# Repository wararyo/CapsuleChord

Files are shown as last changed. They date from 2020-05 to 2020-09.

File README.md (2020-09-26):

# CapsuleChord
An electronic instrument for playing chords, using the M5Stack

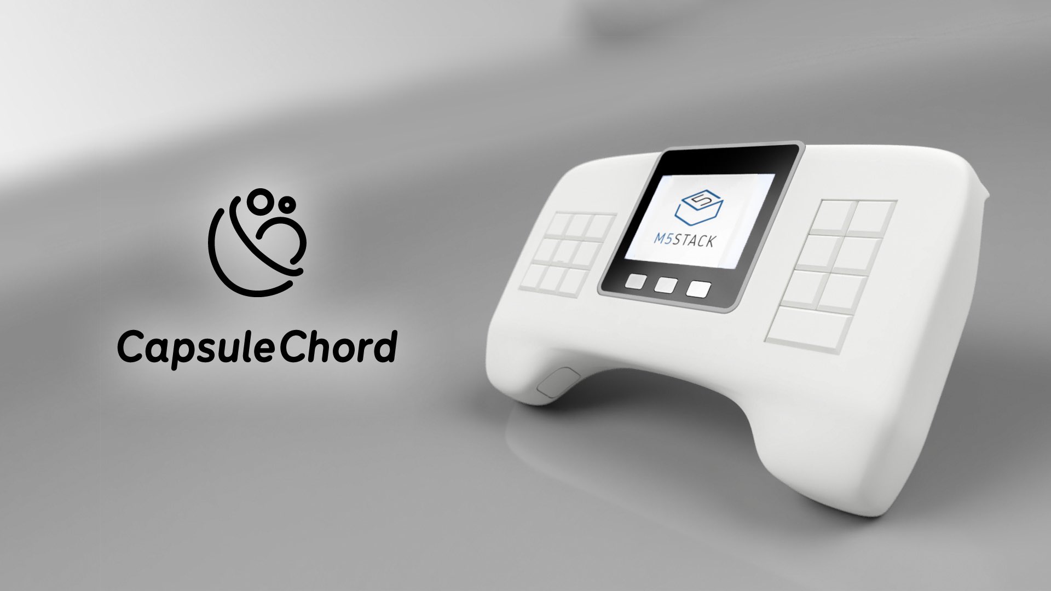
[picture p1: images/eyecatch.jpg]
eyecatch


The firmware in M5Stack is based on [M5Stack_BLEChorder](https://github.com/wararyo/m5chorder).
BLEChorder can be played alone on the M5Stack.

[🎥Introduction Video](https://youtu.be/JE3piJ5rN3A)

Currently this project is in progress.  
The latest information -> [#CapsuleChord](https://twitter.com/search?q=%23CapsuleChord&f=live) (Japanese)

**2020/09/26 3D model files are now available!**  
See `Case` directory.

## Features

* Easy to play chords
* Specify a diatonic code with the left keypad and modify it with the right keypad
* Can be connected with iOS/iPadOS/macOS/Windows via BLE (On Windows, requires MIDIberry and loopMIDI)

## Structure

* M5Stack Gray
* Keypad Controller(ATmega328P)
* Two keypads
* Two function buttons
* Two up-down sliders

## Required to make

### M5Stack

* M5Stack Gray
* M5Stack battery module
* M5Stack proto module

### Keypads

* ATmega328P
* 23 tactile switches
* 8 diodes

### Other

* Two 3pin connectors and sockets
* Two 8pin connectors and sockets
* Six 2M tapping screws (to mount keypads)
* Four 3M tapping scress (to close the casing)
* Two 3M tapping scress (to mount the M5Stack)
* AVRISP of some kind
* and a 3D printing environment :)

## Credits

* [M5TreeView](https://github.com/lovyan03/M5Stack_TreeView) by [lovyan03](https://github.com/lovyan03)
* [M5Stack 3DModel](https://botalab.tech/m5stack_cad_data/) by [botamochi6277](https://botalab.tech/)

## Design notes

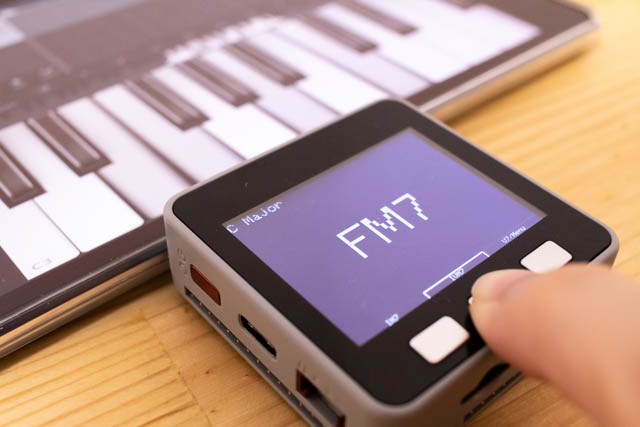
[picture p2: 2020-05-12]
M5Chorder/images/1.thumb.jpg

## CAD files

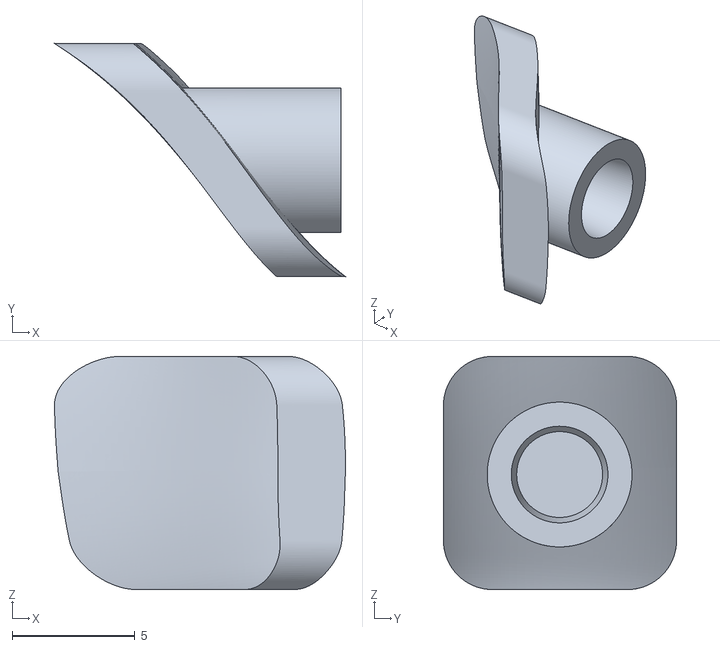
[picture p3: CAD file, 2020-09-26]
Case/sustain-right.stl
11.9 x 9.50 x 9.50

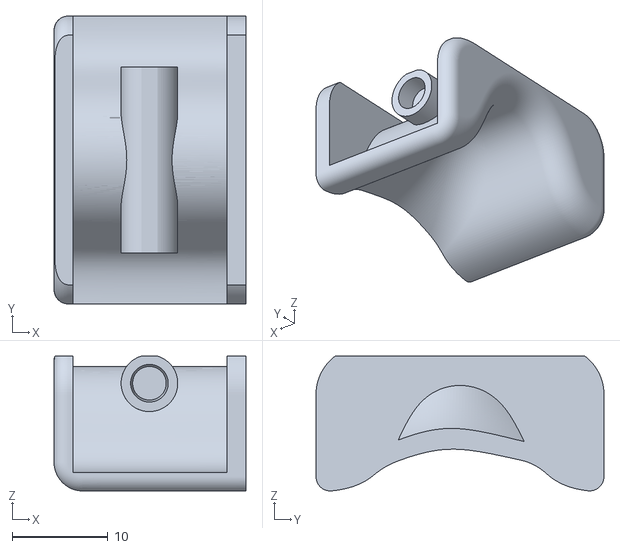
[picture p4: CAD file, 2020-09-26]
Case/back.stl
20.0 x 30.0 x 14.1

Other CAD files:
Case/function-left.stl

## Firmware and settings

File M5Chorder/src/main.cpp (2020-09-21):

#include <M5Stack.h>
#include <vector>
#include <Preferences.h>
#include "M5StackUpdater.h"
#include "BLEMidi.h"
#include "Chord.h"
#include "Scale.h"
#include "Keypad.h"
#include "Menu.h"
#include "KeyMap/KeyMap.h"
#include "Context.h"

#define DEVICE_NAME "BLEChorder"

std::vector<uint8_t> playingNotes;
bool seventh = false;
int option = 0;

// Initialize at setup()
Scale *scale;
int *centerNoteNo;
Context context;

M5ButtonDrawer buttonDrawer;

typedef std::vector<SettingItem*> si;
typedef std::vector<const char *> strs;
Settings settings(si{
  new SettingItemEnum("Mode",{"CapsuleChord","CAmDion","Presets"},0),
  new SettingItemScale("Scale",Scale(0)),
  new SettingItemEnum("Bass",{"None","C1","C2"},0),
  new SettingItemEnum("Voicing",{"Open","Closed"},0),
  new SettingItemNumeric("CenterNoteNo",24,81,60),
  new SettingItemDegreeChord("Custom 1", DegreeChord(4,Chord::Minor|Chord::MajorSeventh)),
  new SettingItemDegreeChord("Custom 2", DegreeChord(5,Chord::Minor|Chord::Seventh)),
  new SettingItem("Keymap",si{
    new SettingItemEnum("Fuction 1",{"Gyro","Sustain","Note","CC"},0),
    new SettingItemEnum("Fuction 2",{"Gyro","Sustain","Note","CC"},1)
  }),
  new SettingItemEnum("SustainBehavior",{"Normal","Trigger"},0)
});

enum Scene : uint8_t {
  Connection,
  Play,
  FunctionMenu,
  length
};

Scene currentScene = Scene::length; //Specify a value other than Connection in order to draw correctly at the first changeScene()
Scene requiredToChangeScene;

void changeScene(Scene scene) {
  //To draw at the end of loop(), set flag
  requiredToChangeScene = scene;
}

//Used only in setup() and the end of loop() Do not touch it anywhere else!
void _changeScene_raw() {
  M5.Lcd.clear();

  //終了処理
  switch(currentScene) {
  }

  //開始処理
  switch(requiredToChangeScene) {
    case Scene::Connection:
      M5.Lcd.setTextFont(1);
      M5.Lcd.setCursor(0, 48);
      M5.Lcd.setTextSize(4);
      M5.Lcd.println("CapsuleChord");
      M5.Lcd.setTextSize(2);
      M5.Lcd.println("BLE MIDI Chordpad Device\n");
      M5.Lcd.setTextSize(1);
      M5.Lcd.println("Advertising...");
      M5.Lcd.println("Press the button A to power off.");
    break;
    case Scene::Play:
      M5.Lcd.setCursor(0,0);
      M5.Lcd.setTextSize(2);
      M5.Lcd.println(scale->toString());
      buttonDrawer.setText(String("Fn"),String("I"),String("Menu"));//TODO:Change it to "Fn, ,Menu"
      buttonDrawer.draw(true);
    break;
    case Scene::FunctionMenu:
      Menu.update(true);
    break;
  }
  currentScene = requiredToChangeScene;
}

void sendNotes(bool isNoteOn, std::vector<uint8_t> notes, int vel) {
  if(isNoteOn) {
    for(uint8_t n : notes) {
      Midi.sendNote(0x90, n, vel);
    }
    playingNotes.insert(playingNotes.end(),notes.begin(),notes.end());
  }
  else {
    for(uint8_t n : playingNotes) {
      Midi.sendNote(0x80, n, 0);
    }
    playingNotes.clear();
  }
}

void playChord(Chord chord) {
  sendNotes(true,chord.toMidiNoteNumbers(*centerNoteNo,16),120);
  M5.Lcd.setTextSize(4);
  M5.Lcd.fillRect(0,60,320,120,BLACK);
  M5.Lcd.setTextDatum(CC_DATUM);
  M5.Lcd.setTextSize(5);
  M5.Lcd.drawString(chord.toString(), 160, 120, 2);
  M5.Lcd.setTextDatum(TL_DATUM);
}

class ServerCallbacks: public BLEMidiServerCallbacks {
    void onConnect(BLEServer* pServer) {
      BLEMidiServerCallbacks::onConnect(pServer);
      changeScene(Scene::Play);
    };

    void onDisconnect(BLEServer* pServer) {
      BLEMidiServerCallbacks::onDisconnect(pServer);
      changeScene(Scene::Connection);
    }
};

void setup() {
  M5.begin();
  Serial.begin(9600);

  //SD Updater
  if(digitalRead(BUTTON_A_PIN) == 0) {
    Serial.println("Will Load menu binary");
    updateFromFS(SD);
    ESP.restart();
  }

  Keypad.begin();
  // Decline speaker noise
  M5.Speaker.begin();
  M5.Speaker.mute();

  // Load settings
  if(!settings.load()){
    Serial.println("settings.json is not found in SD, so I'll try to create it.");
    if(!settings.save()) Serial.println("Setting file creation failed.");
  }

  // Get setting items
  scale = &((SettingItemScale*)settings.findSettingByKey(String("Scale")))->content;
  centerNoteNo = &((SettingItemNumeric*)settings.findSettingByKey(String("CenterNoteNo")))->number;

  // Make Context
  context = Context(&settings);
  context.playChord = playChord;
  context.sendNotes = sendNotes;
  Context::setContext(&context);

  //Menu initialization
  M5ButtonDrawer::width = 106;
  Menu.begin(&settings);

  // Scene initialization
  changeScene(Scene::Connection);
  _changeScene_raw();

  Midi.begin(DEVICE_NAME, new ServerCallbacks(), NULL);
}

void loop() {
  switch(currentScene) {
    case Scene::Connection:
      M5.update();
      if(M5.BtnA.wasPressed()) M5.Power.deepSleep();
    break;
    case Scene::Play:
      M5.update();
      if(M5.BtnC.pressedFor(100)) { //Go to Menu Scene
        sendNotes(false,std::vector<uint8_t>(),120);
        changeScene(Scene::FunctionMenu);
        break;
      }
      
      // if(M5.BtnB.wasPressed()) {
      //   Chord c = scale->getDiatonic(0,Keypad[Key_Seventh].isPressed());
      //   if(Keypad[Key_ThirdInvert].isPressed())   thirdInvert(&c);
      //   if(Keypad[Key_FlatFive].isPressed())     fifthFlat(&c);
      //   if(Keypad[Key_Augment].isPressed())       augment(&c);
      //   if(Keypad[Key_Sus4].isPressed())          sus4(&c);
      //   // if(Keypad[Key_Seventh].isPressed()) thirdInvert(&c);
      //   if(Keypad[Key_SeventhInvert].isPressed()) seventhInvert(&c);
      //   if(Keypad[Key_Ninth].isPressed())         ninth(&c);
      //   if(Keypad[Key_Thirteenth].isPressed())    thirteenth(&c);
      //   playChord(c);
      // }
      if(M5.BtnB.wasReleased()) sendNotes(false,std::vector<uint8_t>(),120);

      Keypad.update();
      KeyMap::getAvailableKeyMaps()[0].get()->update();
      
      buttonDrawer.draw();
    break;
    case Scene::FunctionMenu:
      Menu.update();//Contains M5.update()
      // When requried, back to play scene
      if(Menu.isExitRequired()) {
        Menu.save();
        changeScene(Scene::Play);
      }
    break;
  }
  if(currentScene != requiredToChangeScene) _changeScene_raw();
}

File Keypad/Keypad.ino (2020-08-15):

#include <Wire.h>
#include "Queue.h"
#include "Set.h"

#define I2C_ADDR 0x09

#define sbi(val, bitn)    (val |=(1<<(bitn)))
#define cbi(val, bitn)    (val&=~(1<<(bitn)))
#define tbi(addr,bitn)    addr ^=  (1<<bitn)
#define Get_Bit(val, bitn)    (val &(1<<(bitn)))

/*** TWI Structure ***/
// State(1bit) | Button(7bit)
// State: 0 is pressed, 1 is released
// Button: see the following

/*** Buttons ***/
// Group(3bit) | Button(4bit)

#define PRESSED 0
#define RELEASED 1

// Numbers (Group 1)
#define Custom1 1
#define VIIdim 2
#define Custom2 3
#define IV 4
#define I 5
#define V 6
#define IIm 7
#define VIm 8
#define IIIm 9
// Modifiers (Group 2)
#define Thirteenth    0x10 | 1
#define Ninth         0x10 | 2
#define Sus4          0x10 | 3
#define Augment       0x10 | 4
#define SeventhInvert 0x10 | 5
#define Seventh       0x10 | 6
#define FlatFive      0x10 | 7
#define ThirdInvert   0x10 | 8
// Sliders (Group 3)
#define PitchUp       0x20 | 1
#define PitchDown     0x20 | 2
#define InversionUp   0x20 | 3
#define InversionDown 0x20 | 4
// Function Keys (Group 4)
#define Gyro       0x30 | 1
#define Sustain    0x30 | 2

//TODO: Board1もColumnを出力に、Rowを入力にする

/*** PIN ***/
/* I2C */
// SDA PC4
// SCL PC5
/* Board1 (Numbers) */
// Row1 PD0 OUTPUT
// Row2 PD1 OUTPUT
// Row3 PD2 OUTPUT
// Column1 PD3 INPUT_PULLUP
// Column2 PD4 INPUT_PULLUP
// Column3 PD5 INPUT_PULLUP
/* Board2 (Modifiers) */
// Row1 PB0 INPUT_PULLUP
// Row2 PB1 INPUT_PULLUP
// Row3 PB2 INPUT_PULLUP
// Row4 PB3 INPUT_PULLUP
// Column1 PB4 OUTPUT
// Column2 PB5 OUTPUT
/* Sliders */
// PitchUp PD6 INPUT_PULLUP
// PitchDown PD7 INPUT_PULLUP
// InversionUp PB6 INPUT_PULLUP
// InversionDown PB7 INPUT_PULLUP
/* Functions */
// Gyro PC0 INPUT_PULLUP
// Sustain PC1 INPUT_PULLUP

class ButtonSet : public Set<char> {
  private:
    static char initializer();
    static char validator(char item);
    static char comparator(char a,char b);
  public:
    ButtonSet(int size = 256) : Set(size,initializer,validator,comparator){}
};
char ButtonSet::initializer() {
  return 0;//Since there is no 0 in the button ID, 0 is used instead of NULL.
}
char ButtonSet::validator(char item){
  //0 is invalid because there is no 0 in the button ID.
  return ((item & 0b01111111) != 0) ? 1 : 0;
}
char ButtonSet::comparator(char a,char b) {
  if(a == NULL || b == NULL) return 0;
  return (a == b) ? 1 : 0;
}

void setup()
{
  Wire.begin(I2C_ADDR);
  Wire.onRequest(requestEvent);
  matrixInit();
  cbi(DDRD,6);//PitchUp
  cbi(DDRD,7);//PitchDown
  cbi(DDRB,6);//InversionUp
  cbi(DDRB,7);//InversionDown
  cbi(DDRC,0);//Gyro
  cbi(DDRC,1);//Sustain
  sbi(PORTD,6);//PitchUp
  sbi(PORTD,7);//PitchDown
  sbi(PORTB,6);//InversionUp
  sbi(PORTB,7);//InversionDown
  sbi(PORTC,0);//Gyro
  sbi(PORTC,1);//Sustain
}

void matrixInit() {
  DDRD &= ~(0b00111000); //cbi INPUT
  DDRD |=  (0b00000111); //sbi OUTPUT
  PORTD &= ~(0b00000000); //cbi
  PORTD |=  (0b00111111); //sbi

  DDRB &= ~(0b00001111); //cbi INPUT
  DDRB |=  (0b00110000); //sbi OUTPUT
  PORTB &= ~(0b00000000); //cbi
  PORTB |=  (0b00111111); //sbi
}

Queue<char> events = Queue<char>(); //Data to be sent to the host
ButtonSet pressing = ButtonSet(8); //The buttons currently pressed

void requestEvent()
{
  if(events.count() != 0) Wire.write(events.pop());
  return;
}

void setKey(char state, char button) {
  state = (state != 0) ? PRESSED : RELEASED;
  char event = (state & 1) << 7 | button & 0b01111111;
  switch(state){
    case PRESSED:
      if(pressing.Add(button)) events.push(event);
    break;
    case RELEASED:
      if(pressing.Remove(button)) events.push(event);
    break;
  }
}

void loop()
{
  /* Board1 */
  // Row 1
  PORTD &= ~(0b001); //cbi
  PORTD |=  (0b110); //sbi
  delay(1);
  setKey(bit_is_clear(PIND,3),Custom1);
  setKey(bit_is_clear(PIND,4),VIIdim);
  setKey(bit_is_clear(PIND,5),Custom2);
  delay(1);

  // Row 2
  PORTD &= ~(0b010); //cbi
  PORTD |=  (0b101); //sbi
  delay(1);
  setKey(bit_is_clear(PIND,3),IV);
  setKey(bit_is_clear(PIND,4),I);
  setKey(bit_is_clear(PIND,5),V);
  delay(1);

  // Row 3
  PORTD &= ~(0b100); //cbi
  PORTD |=  (0b011); //sbi
  delay(1);
  setKey(bit_is_clear(PIND,3),IIm);
  setKey(bit_is_clear(PIND,4),VIm);
  setKey(bit_is_clear(PIND,5),IIIm);
  delay(2);

  /* Board2 */
  // Column 1
  PORTB &= ~(0b010000); //cbi
  PORTB |=  (0b100000); //sbi
  delay(1);
  setKey(bit_is_clear(PINB,0),Ninth);
  setKey(bit_is_clear(PINB,1),SeventhInvert);
  setKey(bit_is_clear(PINB,2),Augment);
  setKey(bit_is_clear(PINB,3),FlatFive);
  delay(1);

  // Column 2
  PORTB &= ~(0b100000); //cbi
  PORTB |=  (0b010000); //sbi
  delay(1);
  setKey(bit_is_clear(PINB,0),Thirteenth);
  setKey(bit_is_clear(PINB,1),Seventh);
  setKey(bit_is_clear(PINB,2),Sus4);
  setKey(bit_is_clear(PINB,3),ThirdInvert);
  delay(2);

  /* Other */
  setKey(bit_is_set(PIND,6),PitchUp);
  setKey(bit_is_set(PIND,7),PitchDown);
  setKey(bit_is_set(PINB,6),InversionUp);
  setKey(bit_is_set(PINB,7),InversionDown);
  setKey(bit_is_set(PINC,0),Gyro);
  setKey(bit_is_set(PINC,1),Sustain);
  delay(2);
}

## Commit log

2020-05-10 とりあえずキーパッドの押下を認識
2020-05-10 QuueとButtonSetを実装した
2020-05-10 I2Cを使った伝達完成
2020-05-10 すべてのボタンを定義&読み取り
2020-05-10 Numberキー以外を一時的に無効化
2020-05-10 M5ChorderがKeypadにとりあえず対応した
2020-05-13 separated the menu (currently it won't work)
    [main.cpp]
2020-05-23 Implement setting items and SettingItem classes but...
    it won't work
    [main.cpp]
2020-05-29 Rename fromDegree to degreeToChord
    よく考えたらfromDegreeだったらDegreeからScaleBaseを生成する関数になっちゃうぞ！
2020-06-20 Fix: Board2 doesn't inteact
    [Keypad.ino]
2020-09-06 Introducing the concept of modes (but it's not working...)
    [main.cpp]
2020-09-26 Add 3d model files
    [back.stl, function-left.stl, sustain-right.stl]
